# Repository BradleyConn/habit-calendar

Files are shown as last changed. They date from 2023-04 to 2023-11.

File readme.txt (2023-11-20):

This project contains everything used to construct a Habit Calender inspired from Simone Geirtz https://yetch.store/products/every-day-goal-calendar

This project contains the PCB designs designed in kicad as well as BOM and position files that wer sent off to JLCPCB for manufacturing.

Each board cost around $4 to make and ship and contains two PY32F002A microcontrollers and 32 lights/buttons. It takes 16 boards to make a full 365 day calendar.

The lights are ws2812b which provide endless lighting possibilities to be used outside of a calender concept. The LEDs can be controlled from the microcontroller with a bitbanged driver. A neat accomplishment from a super cheap 8 MHz microcontroller.

This wasn't intended to be public facing yet so the code is somewhat messy from when I was just trying to protoype stuff out, and documentation is not the best. In the software folder, the standalone folder is what you want, but check the readme for helpful info. Hopefully I can find some time to clean everything up.

More information and pictures can be found on www.bradleyconn.space
I need to properly cross link everything still. Sorry about that.

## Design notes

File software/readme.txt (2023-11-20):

Different project options. Just move the main.c file into the User folder in the submodule and build from there.

Use pico to load code onto board.
XXX: TO PROGRAM MUST CONNECT TO 3.3V!!! (Not 5V)
Connect pico pin GP3 to PA14
Connect pico pin GP2 to PA13
`sudo make flash`
erase with `sudo pyocd erase -t py32f002ax5 --chip --config ./Misc/pyocd.yaml`

may need to rebase the template submodule to 4c9de4301e8855a. That's where I was working from in development. New commits untested.

- Standalone has each micrcontroller controlling their own leds. No central control.
    - Probably only want to keep PF0 or PF1 resistors which connects micro to LED Din, remove the 7 others

(Work In Progress)
XXX: Turns out for the 002a version there's only tx or rx on a pin, not both... i2c could be an option if slave mode actually works but I'm unsure with the chinese datasheet. The english datasheet is for the 030 or 003 parts. Bitbang uart is probably the best option with interrupts for nonblocking. Probably ditch polling, and just have one way comms.
- Pico master, each micro gets polled for it's state over a uart chain and pico controls the LEDs 
    - Each micro needs a different ID
    - Top and bottom micro have different code (see below), but same code board to board (except for ID)
    - Remove all the micro<->LED resistors
    - Top micro remove PF0 resistor
        - Same board micro to micro half duplex over PF1
    - Bottom micro remove PF0 resistor
        - Board to board half duplex over PF0
    - So resistors should be
        - So no horizontal resistors
        - Top micro veritcal resistors should be DNP, DNP, P (boot), DNP, DNP, P (PF1)
        - Bottom micro veritcal resistors should be DNP, DNP, P (boot), DNP, P (PF0), DNP

- Pico master with wled option
    - wip but use a toggle switch to switch who controls the ws2812b line

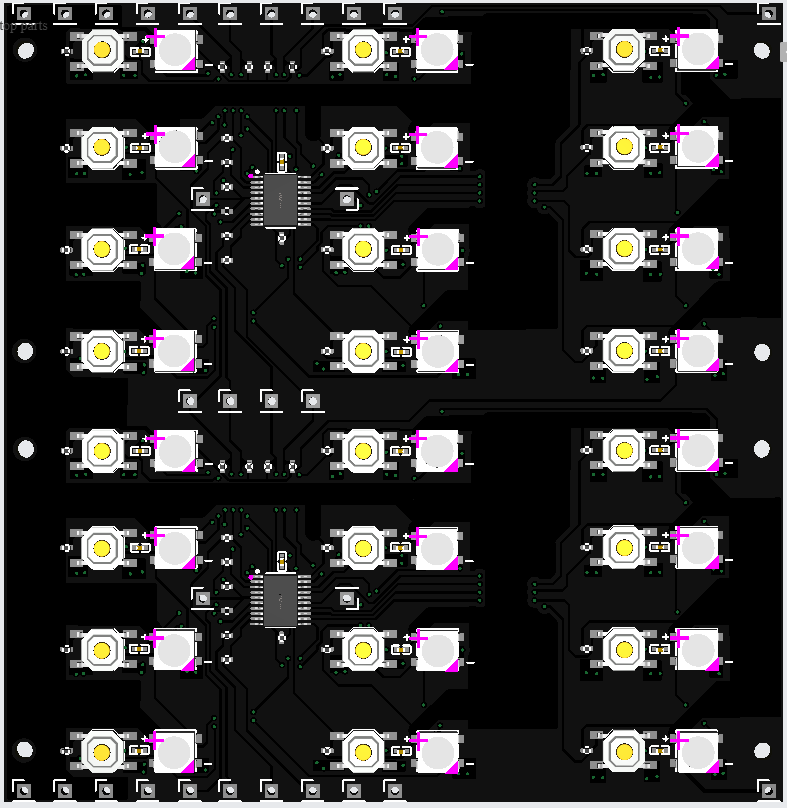
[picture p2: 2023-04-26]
images/3d-model-front.png

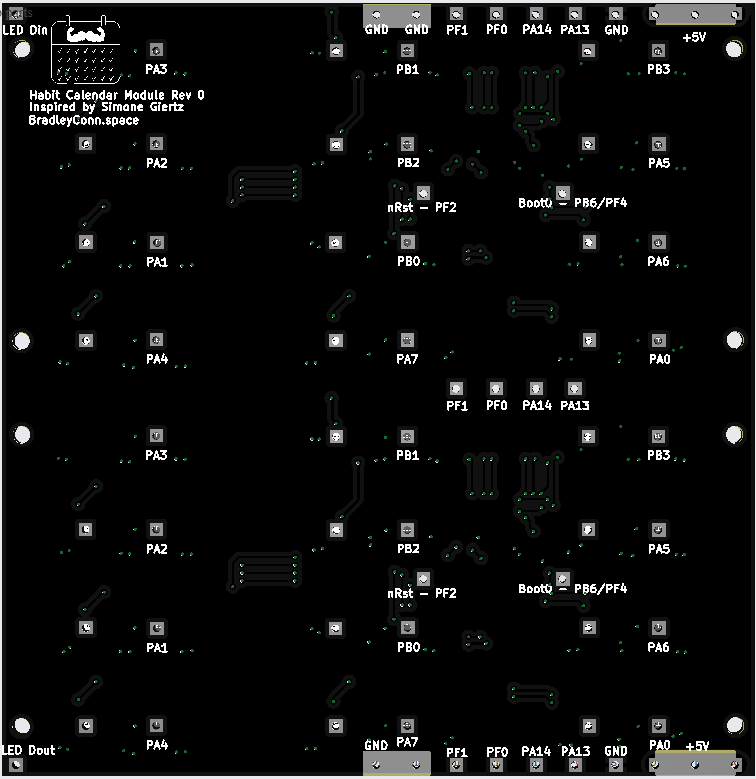
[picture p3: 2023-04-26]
images/3d-model-back.png

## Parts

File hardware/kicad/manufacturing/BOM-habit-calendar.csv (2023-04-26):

Comment | Designator | Footprint | LCSC
100nf | C1,C10,C11,C12,C14,C15,C16,C17,C18,C19,C2,C20,C21,C22,C23,C24,C25,C3,C4,C5,C6,C7,C8,C9 | C0402 | C1525
XL-5050RGBC-WS2812B | LED1,LED10,LED11,LED12,LED13,LED14,LED15,LED16,LED17,LED18,LED19,LED2,LED20,LED21,LED22,LED23,LED24,LED3,LED4,LED5,LED6,LED7,LED8,LED9 | LED-SMD_4P-L5.0-W5.0-BL_XL-5050RGBC | C2843785
TS-1187A-B-A-B | SW1,SW10,SW11,SW12,SW13,SW14,SW15,SW16,SW17,SW18,SW19,SW2,SW20,SW21,SW22,SW23,SW24,SW3,SW4,SW5,SW6,SW7,SW8,SW9 | SW-SMD_4P-L5.1-W5.1-P3.70-LS6.5-TL-2 | C318884
PY32F002AF15P6TU | U1,U2 | TSSOP-20_L6.5-W4.4-P0.65-LS6.4-BL | C5292059
Conn_01x01 | J78 | PinHeader_1x01_P2.54mm_Vertical
Conn_01x01 | J77 | PinHeader_1x01_P2.54mm_Vertical
Conn_01x01 | J76 | PinHeader_1x01_P2.54mm_Vertical
Conn_01x01 | J75 | PinHeader_1x01_P2.54mm_Vertical
10k | R46 | R_0402_1005Metric
10k | R45 | R_0402_1005Metric
0 ohm | R44 | R_0402_1005Metric
0 ohm | R43 | R_0402_1005Metric
0 ohm | R42 | R_0402_1005Metric
0 ohm | R41 | R_0402_1005Metric
10k | R40 | R_0402_1005Metric
10k | R39 | R_0402_1005Metric
10k | R38 | R_0402_1005Metric
10k | R37 | R_0402_1005Metric
10k | R36 | R_0402_1005Metric
10k | R35 | R_0402_1005Metric
10k | R34 | R_0402_1005Metric
10k | R33 | R_0402_1005Metric
DNP | R32 | R_0402_1005Metric
10k | R31 | R_0402_1005Metric
0 ohm | R30 | R_0402_1005Metric
0 ohm | R29 | R_0402_1005Metric
10k | R28 | R_0402_1005Metric
0 ohm | R27 | R_0402_1005Metric
0 ohm | R26 | R_0402_1005Metric
10k | R25 | R_0402_1005Metric
10k | R24 | R_0402_1005Metric
Conn_01x01 | J98 | PinHeader_1x01_P2.54mm_Vertical
Conn_01x01 | J97 | PinHeader_1x01_P2.54mm_Vertical
Conn_01x01 | J96 | PinHeader_1x01_P2.54mm_Vertical
Conn_01x01 | J95 | PinHeader_1x01_P2.54mm_Vertical
Conn_01x01 | J94 | PinHeader_1x01_P2.54mm_Vertical
Conn_01x01 | J93 | PinHeader_1x01_P2.54mm_Vertical
Conn_01x01 | J92 | PinHeader_1x01_P2.54mm_Vertical
Conn_01x01 | J91 | PinHeader_1x01_P2.54mm_Vertical
Conn_01x01 | J90 | PinHeader_1x01_P2.54mm_Vertical
Conn_01x01 | J89 | PinHeader_1x01_P2.54mm_Vertical
Conn_01x01 | J62 | PinHeader_1x01_P2.54mm_Vertical
Conn_01x01 | J61 | PinHeader_1x01_P2.54mm_Vertical
Conn_01x01 | J59 | PinHeader_1x01_P2.54mm_Vertical
Conn_01x01 | J58 | PinHeader_1x01_P2.54mm_Vertical
Conn_01x01 | J57 | PinHeader_1x01_P2.54mm_Vertical
Conn_01x01 | J56 | PinHeader_1x01_P2.54mm_Vertical
Conn_01x01 | J55 | PinHeader_1x01_P2.54mm_Vertical
Conn_01x01 | J54 | PinHeader_1x01_P2.54mm_Vertical
Conn_01x01 | J53 | PinHeader_1x01_P2.54mm_Vertical
Conn_01x01 | J52 | PinHeader_1x01_P2.54mm_Vertical
Conn_01x01 | J50 | PinHeader_1x01_P2.54mm_Vertical
Conn_01x01 | J49 | PinHeader_1x01_P2.54mm_Vertical
Conn_01x01 | J47 | PinHeader_1x01_P2.54mm_Vertical
Conn_01x01 | J46 | PinHeader_1x01_P2.54mm_Vertical
Conn_01x01 | J45 | PinHeader_1x01_P2.54mm_Vertical
Conn_01x01 | J44 | PinHeader_1x01_P2.54mm_Vertical
Conn_01x01 | J43 | PinHeader_1x01_P2.54mm_Vertical
Conn_01x01 | J41 | PinHeader_1x01_P2.54mm_Vertical
Conn_01x01 | J40 | PinHeader_1x01_P2.54mm_Vertical
Conn_01x01 | J38 | PinHeader_1x01_P2.54mm_Vertical
Conn_01x01 | J37 | PinHeader_1x01_P2.54mm_Vertical
Conn_01x01 | J36 | PinHeader_1x01_P2.54mm_Vertical
Conn_01x01 | J35 | PinHeader_1x01_P2.54mm_Vertical
Conn_01x01 | J34 | PinHeader_1x01_P2.54mm_Vertical
Conn_01x01 | J33 | PinHeader_1x01_P2.54mm_Vertical
Conn_01x01 | J32 | PinHeader_1x01_P2.54mm_Vertical
MountingHole | H8 | MountingHole_2.2mm_M2
MountingHole | H7 | MountingHole_2.2mm_M2
MountingHole | H6 | MountingHole_2.2mm_M2
MountingHole | H5 | MountingHole_2.2mm_M2
100nf | C26 | C0402
Conn_01x01 | J10 | PinHeader_1x01_P2.54mm_Vertical
10k | R19 | R_0402_1005Metric
Conn_01x01 | J63 | PinHeader_1x01_P2.54mm_Vertical
Conn_01x01 | J67 | PinHeader_1x01_P2.54mm_Vertical
Conn_01x01 | J21 | PinHeader_1x01_P2.54mm_Vertical
Conn_01x01 | J5 | PinHeader_1x01_P2.54mm_Vertical
Conn_01x01 | J15 | PinHeader_1x01_P2.54mm_Vertical
10k | R9 | R_0402_1005Metric
0 ohm | R22 | R_0402_1005Metric
Conn_01x01 | J9 | PinHeader_1x01_P2.54mm_Vertical
10k | R13 | R_0402_1005Metric
0 ohm | R14 | R_0402_1005Metric
Conn_01x01 | J2 | PinHeader_1x01_P2.54mm_Vertical
Conn_01x01 | J20 | PinHeader_1x01_P2.54mm_Vertical
Conn_01x01 | J30 | PinHeader_1x01_P2.54mm_Vertical
Conn_01x01 | J22 | PinHeader_1x01_P2.54mm_Vertical
Conn_01x01 | J13 | PinHeader_1x01_P2.54mm_Vertical
10k | R8 | R_0402_1005Metric
Conn_01x01 | J31 | PinHeader_1x01_P2.54mm_Vertical
Conn_01x01 | J11 | PinHeader_1x01_P2.54mm_Vertical
MountingHole | H1 | MountingHole_2.2mm_M2
Conn_01x01 | J1 | PinHeader_1x01_P2.54mm_Vertical
Conn_01x01 | J66 | PinHeader_1x01_P2.54mm_Vertical
MountingHole | H2 | MountingHole_2.2mm_M2
MountingHole | H3 | MountingHole_2.2mm_M2
0 ohm | R20 | R_0402_1005Metric
Conn_01x01 | J29 | PinHeader_1x01_P2.54mm_Vertical
10k | R2 | R_0402_1005Metric
10k | R10 | R_0402_1005Metric
10k | R18 | R_0402_1005Metric
10k | R11 | R_0402_1005Metric
Conn_01x01 | J4 | PinHeader_1x01_P2.54mm_Vertical
100nf | C13 | C0402
Conn_01x01 | J65 | PinHeader_1x01_P2.54mm_Vertical
DNP | R7 | R_0402_1005Metric
Conn_01x01 | J18 | PinHeader_1x01_P2.54mm_Vertical
MountingHole | H4 | MountingHole_2.2mm_M2
0 ohm | R12 | R_0402_1005Metric
Conn_01x01 | J27 | PinHeader_1x01_P2.54mm_Vertical
10k | R17 | R_0402_1005Metric
10k | R1 | R_0402_1005Metric
Conn_01x01 | J6 | PinHeader_1x01_P2.54mm_Vertical
0 ohm | R23 | R_0402_1005Metric
Conn_01x01 | J25 | PinHeader_1x01_P2.54mm_Vertical
0 ohm | R4 | R_0402_1005Metric
Conn_01x01 | J26 | PinHeader_1x01_P2.54mm_Vertical
Conn_01x01 | J16 | PinHeader_1x01_P2.54mm_Vertical
10k | R16 | R_0402_1005Metric
Conn_01x01 | J64 | PinHeader_1x01_P2.54mm_Vertical
10k | R6 | R_0402_1005Metric
Conn_01x01 | J51 | PinHeader_1x01_P2.54mm_Vertical
Conn_01x01 | J12 | PinHeader_1x01_P2.54mm_Vertical
Conn_01x01 | J68 | PinHeader_1x01_P2.54mm_Vertical
Conn_01x01 | J24 | PinHeader_1x01_P2.54mm_Vertical
0 ohm | R21 | R_0402_1005Metric
10k | R15 | R_0402_1005Metric
Conn_01x01 | J60 | PinHeader_1x01_P2.54mm_Vertical
Conn_01x01 | J17 | PinHeader_1x01_P2.54mm_Vertical
Conn_01x01 | J8 | PinHeader_1x01_P2.54mm_Vertical
0 ohm | R5 | R_0402_1005Metric
10k | R3 | R_0402_1005Metric
Conn_01x01 | J7 | PinHeader_1x01_P2.54mm_Vertical
Conn_01x01 | J19 | PinHeader_1x01_P2.54mm_Vertical
Conn_01x01 | J14 | PinHeader_1x01_P2.54mm_Vertical

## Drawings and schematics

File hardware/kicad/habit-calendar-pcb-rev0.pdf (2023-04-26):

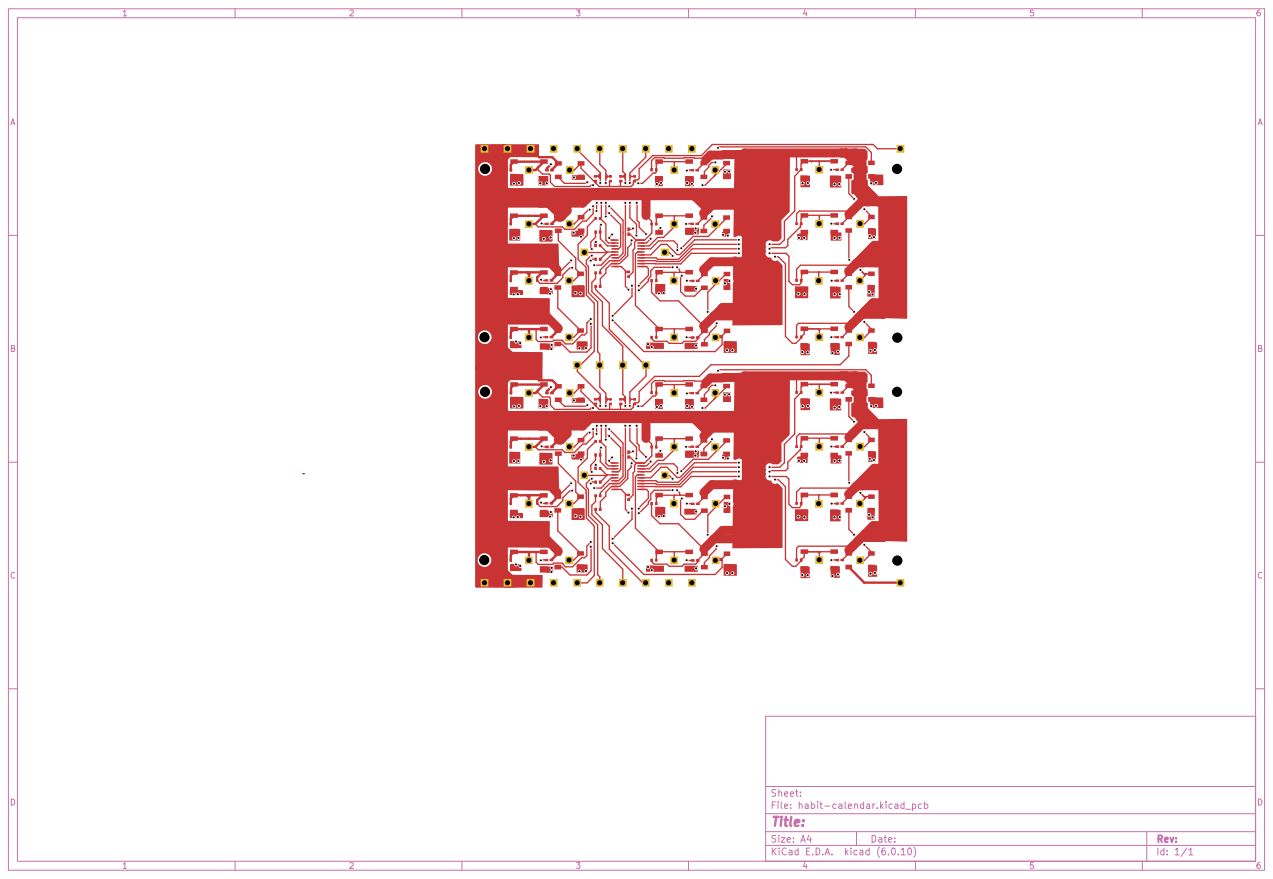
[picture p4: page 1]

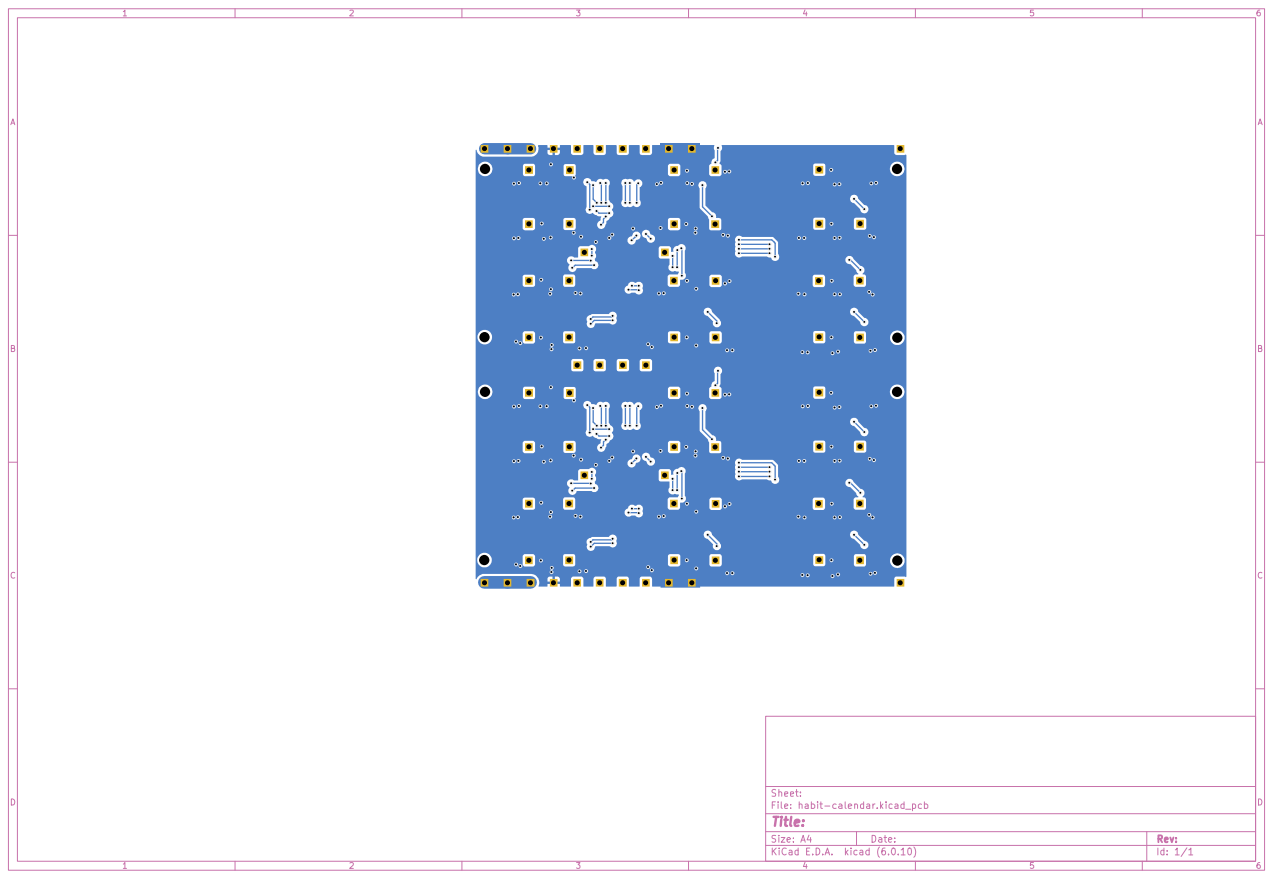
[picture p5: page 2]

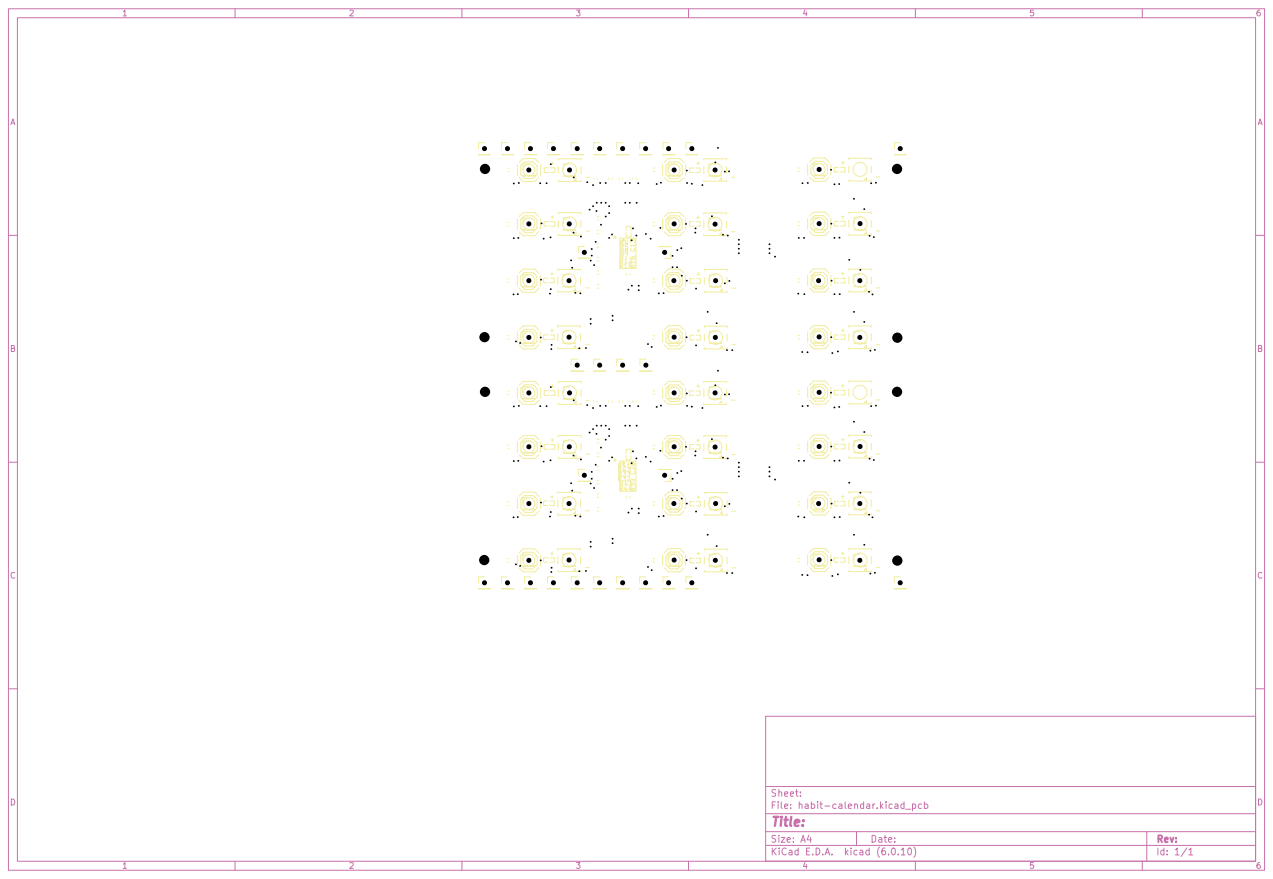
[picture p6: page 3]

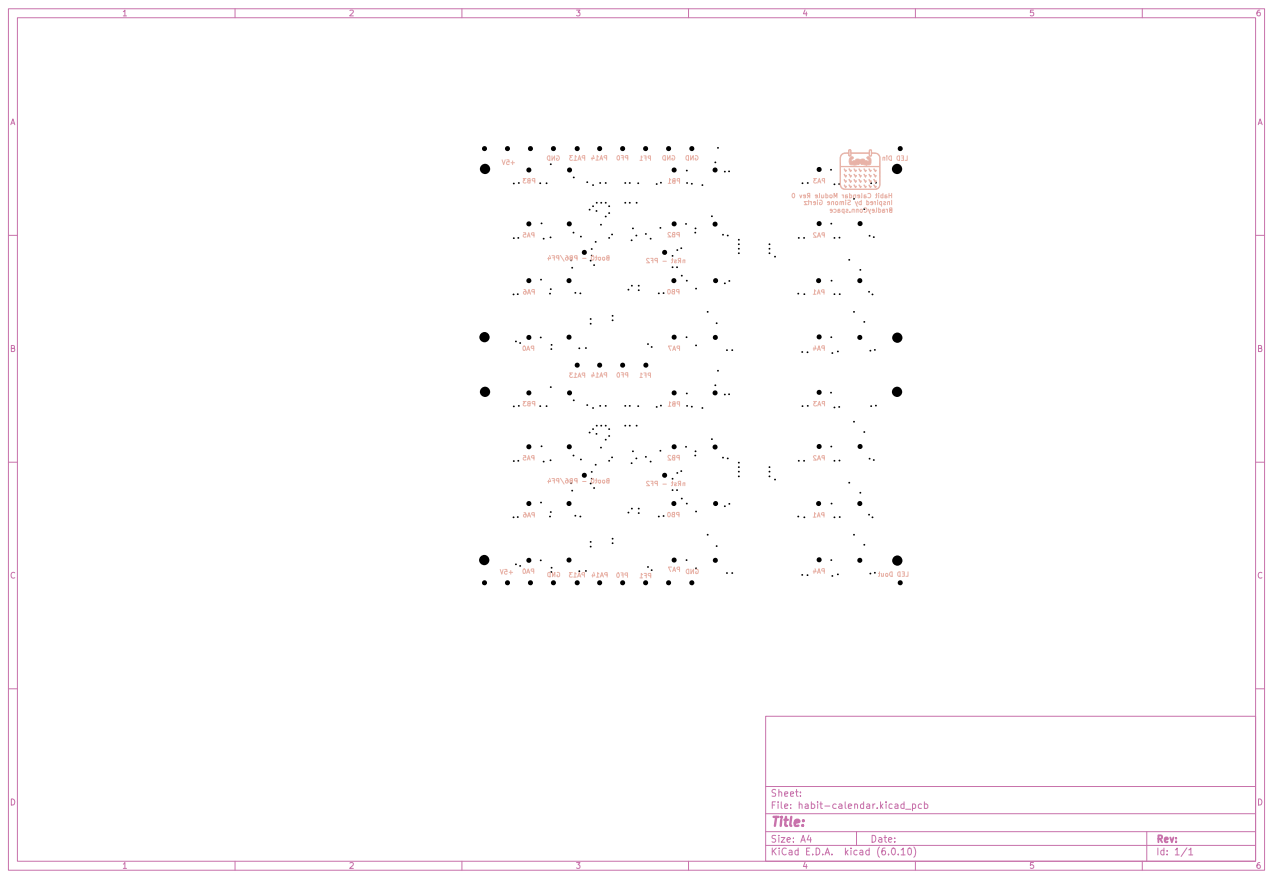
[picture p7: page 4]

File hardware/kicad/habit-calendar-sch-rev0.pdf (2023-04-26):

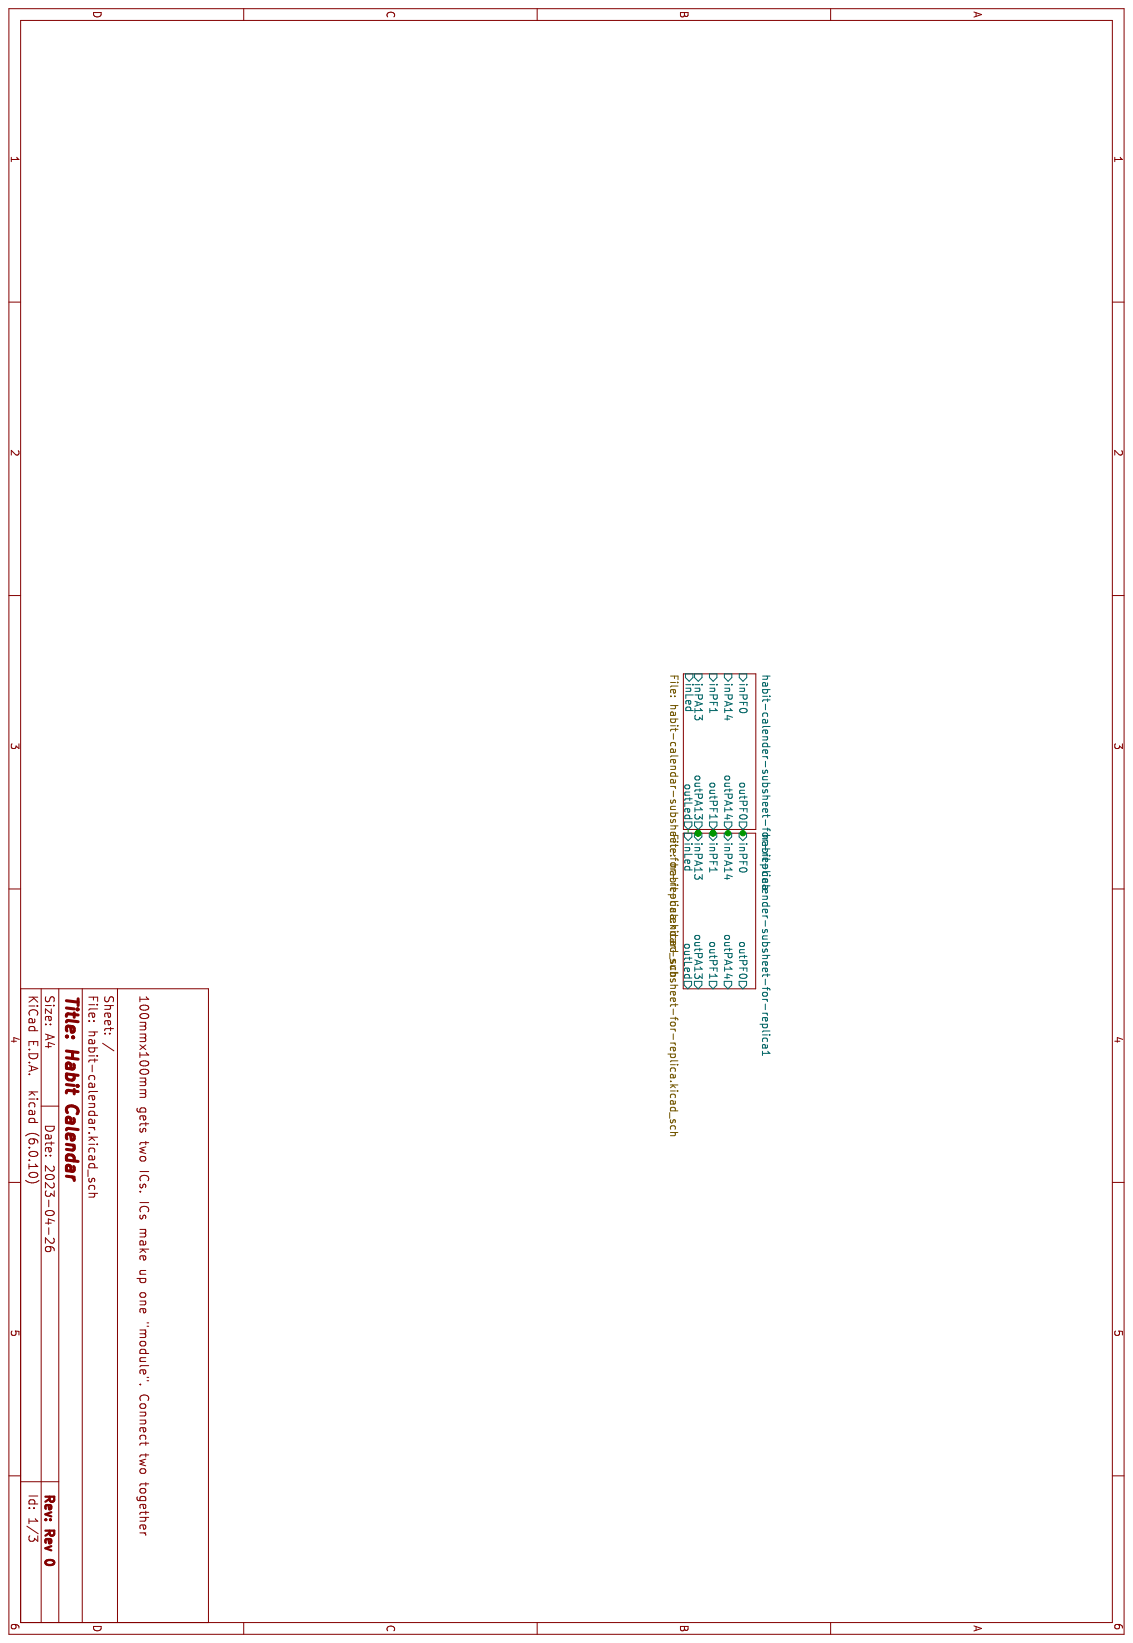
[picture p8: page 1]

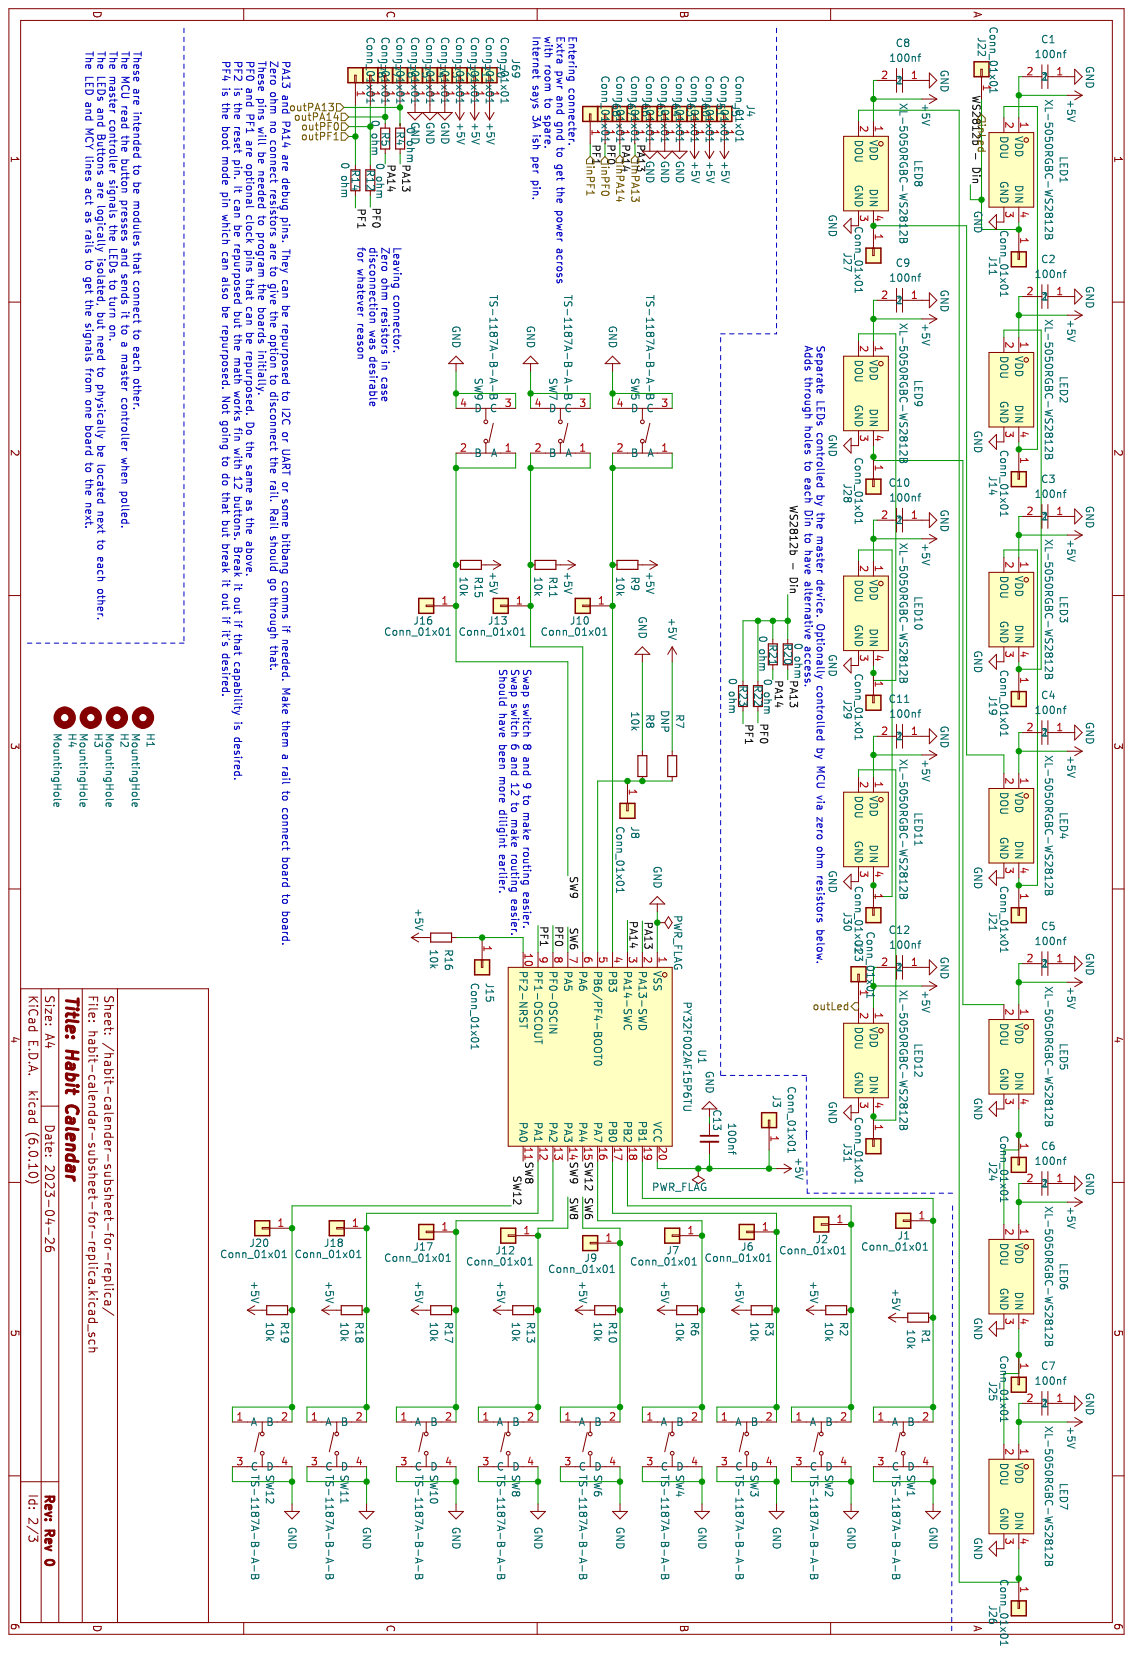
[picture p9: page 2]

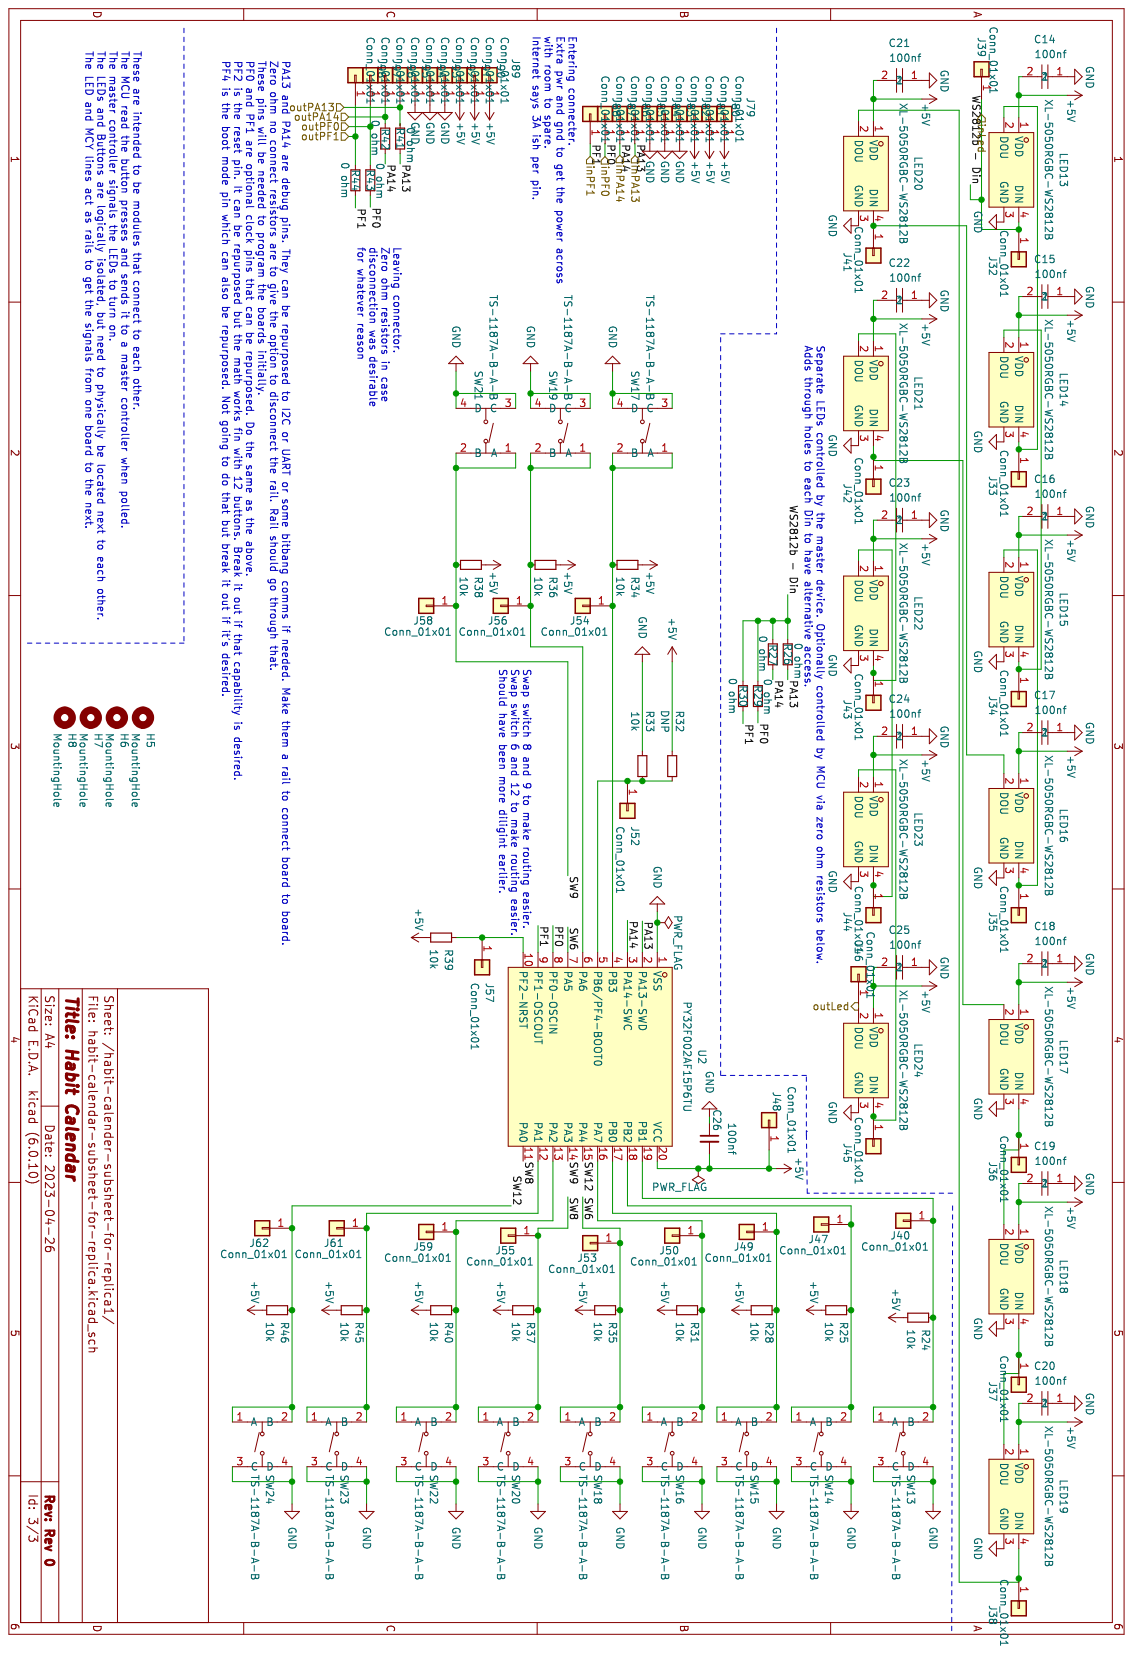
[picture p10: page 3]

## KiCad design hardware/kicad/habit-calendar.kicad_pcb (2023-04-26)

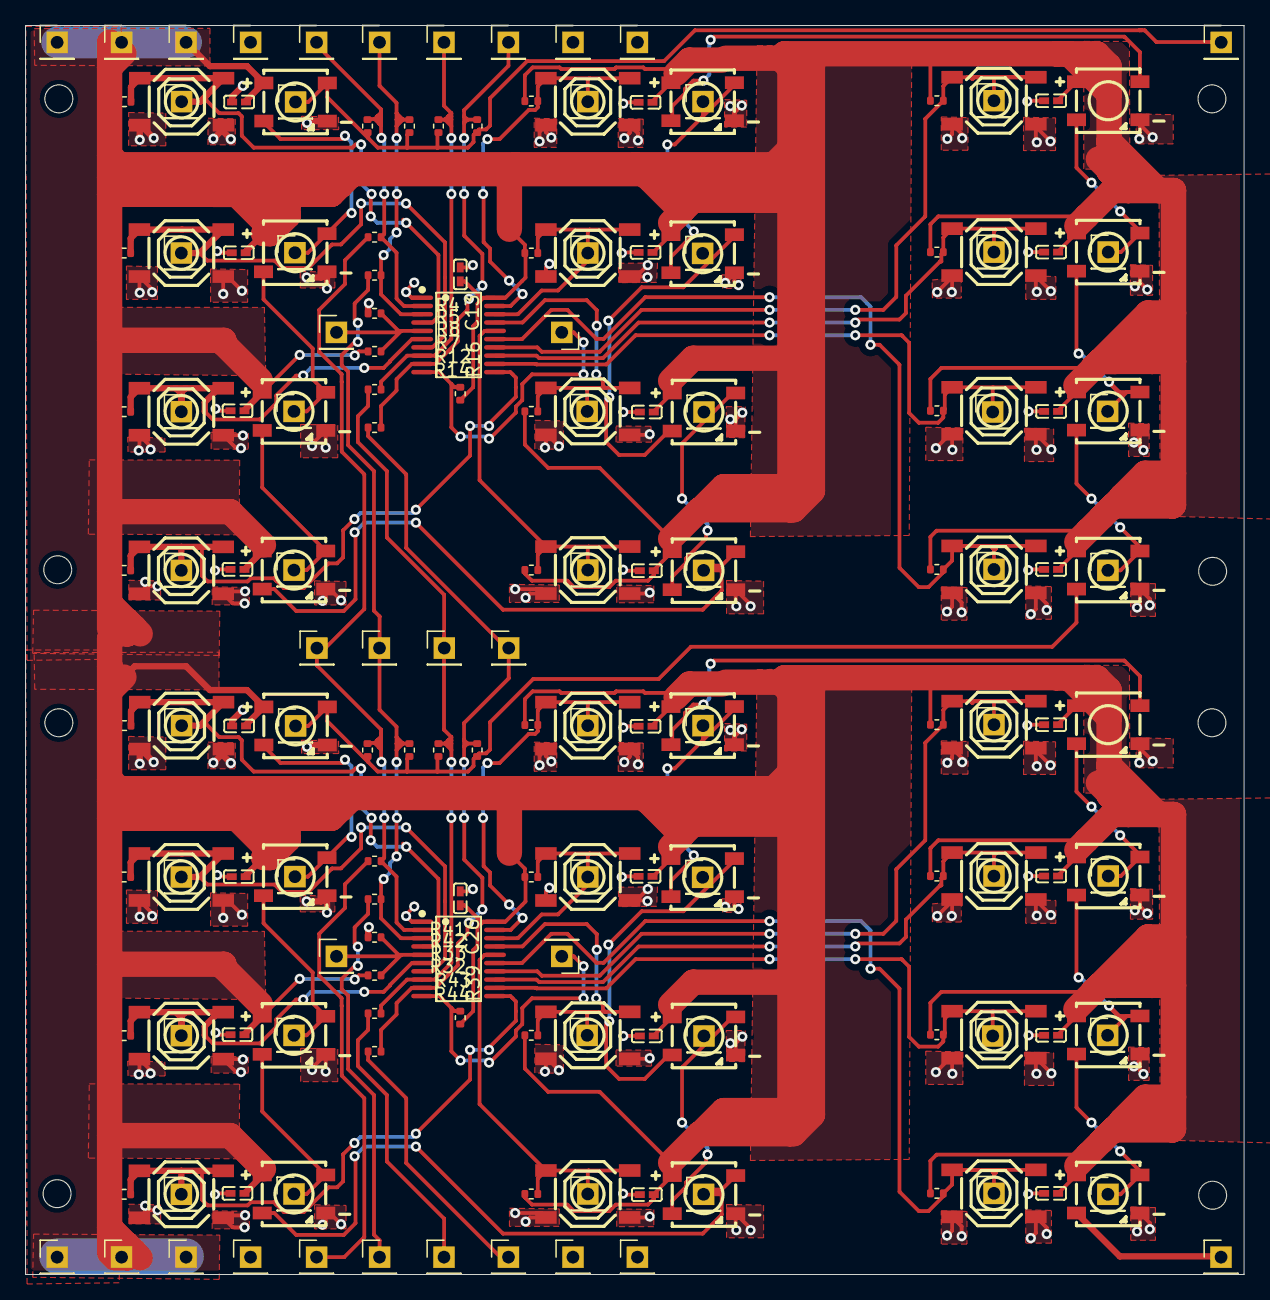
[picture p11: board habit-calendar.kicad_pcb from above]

Board: 2 copper layers, 96.0 x 98.4 mm, 206 parts (0 on the bottom side), 67 nets.

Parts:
C1, C2, C3, C4, C5, C6, C7, C8, C9, C10, C11, C12, C13, C14, C15, C16, C17, C18, C19, C20, C21, C22, C23, C24, C25, C26: 100nf; C0402
H1, H2, H3, H4, H5, H6, H7, H8: MountingHole; MountingHole_2.2mm_M2
J1, J2, J4, J5, J6, J7, J8, J9, J10, J11, J12, J13, J14, J15, J16, J17, J18, J19, J20, J21, J22, J24, J25, J26, J27, J29, J30, J31, J32, J33, J34, J35, J36, J37, J38, J40, J41, J43, J44, J45, J46, J47, J49, J50, J51, J52, J53, J54, J55, J56, J57, J58, J59, J60, J61, J62, J63, J64, J65, J66, J67, J68, J75, J76, J77, J78, J89, J90, J91, J92, J93, J94, J95, J96, J97, J98: Conn_01x01; PinHeader_1x01_P2.54mm_Vertical
LED1, LED2, LED3, LED4, LED5, LED6, LED7, LED8, LED9, LED10, LED11, LED12, LED13, LED14, LED15, LED16, LED17, LED18, LED19, LED20, LED21, LED22, LED23, LED24: XL-5050RGBC-WS2812B; LED-SMD_4P-L5.0-W5.0-BL_XL-5050RGBC
R1, R2, R3, R6, R8, R9, R10, R11, R13, R15, R16, R17, R18, R19, R24, R25, R28, R31, R33, R34, R35, R36, R37, R38, R39, R40, R45, R46: 10k; R_0402_1005Metric
R4, R5, R12, R14, R20, R21, R22, R23, R26, R27, R29, R30, R41, R42, R43, R44: 0 ohm; R_0402_1005Metric
R7, R32: DNP; R_0402_1005Metric
SW1, SW2, SW3, SW4, SW5, SW6, SW7, SW8, SW9, SW10, SW11, SW12, SW13, SW14, SW15, SW16, SW17, SW18, SW19, SW20, SW21, SW22, SW23, SW24: TS-1187A-B-A-B; SW-SMD_4P-L5.1-W5.1-P3.70-LS6.5-TL-2
U1, U2: PY32F002AF15P6TU; TSSOP-20_L6.5-W4.4-P0.65-LS6.4-BL

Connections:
+5V: C1.2, C2.2, C3.2, C4.2, C5.2, C6.2, C7.2, C8.2, C9.2, C10.2, C11.2, C12.2, C13.2, C14.2, C15.2, C16.2, C17.2, C18.2, C19.2, C20.2, C21.2, C22.2, C23.2, C24.2, C25.2, C26.2, J4.1, J5.1, J51.1, J89.1, J90.1, J91.1, LED1.1 (VDD), LED2.1 (VDD), LED3.1 (VDD), LED4.1 (VDD), LED5.1 (VDD), LED6.1 (VDD), LED7.1 (VDD), LED8.1 (VDD), LED9.1 (VDD), LED10.1 (VDD), LED11.1 (VDD), LED12.1 (VDD), LED13.1 (VDD), LED14.1 (VDD), LED15.1 (VDD), LED16.1 (VDD), LED17.1 (VDD), LED18.1 (VDD), LED19.1 (VDD), LED20.1 (VDD), LED21.1 (VDD), LED22.1 (VDD), LED23.1 (VDD), LED24.1 (VDD), R1.2, R2.2, R3.2, R6.2, R7.1, R9.2, R10.2, R11.2, R13.2, R15.2, R16.2, R17.2, R18.2, R19.2, R24.2, R25.2, R28.2, R31.2, R32.1, R34.2, R35.2, R36.2, R37.2, R38.2, R39.2, R40.2, R45.2, R46.2, U1.20 (VCC), U2.20 (VCC)
/habit-calender-subsheet-for-replica1/PA13: J75.1, R4.1, R26.2, R41.2, U2.2 (PA13-SWD)
/habit-calender-subsheet-for-replica1/PA14: J76.1, R5.1, R27.2, R42.2, U2.3 (PA14-SWC)
/habit-calender-subsheet-for-replica1/PF0: J77.1, R12.1, R29.2, R43.2, U2.8 (PF0-OSCIN)
/habit-calender-subsheet-for-replica1/PF1: J78.1, R14.1, R30.2, R44.2, U2.9 (PF1-OSCOUT)
/habit-calender-subsheet-for-replica1/SW6: J53.1, R35.1, SW18.1 (A), SW18.2 (B), U2.7 (PA5)
/habit-calender-subsheet-for-replica1/SW8: J55.1, R37.1, SW20.1 (A), SW20.2 (B), U2.11 (PA0)
/habit-calender-subsheet-for-replica1/SW9: J58.1, R38.1, SW21.1 (A), SW21.2 (B), U2.14 (PA3)
/habit-calender-subsheet-for-replica1/SW12: J62.1, R46.1, SW24.1 (A), SW24.2 (B), U2.15 (PA4)
/habit-calender-subsheet-for-replica1/WS2812b - Din: J32.1, LED12.2 (DOU), LED13.4 (DIN), R26.1, R27.1, R29.1, R30.1
/habit-calender-subsheet-for-replica1/outLed: J46.1, LED24.2 (DOU)
/habit-calender-subsheet-for-replica1/outPA13: J95.1, R41.1
/habit-calender-subsheet-for-replica1/outPA14: J96.1, R42.1
/habit-calender-subsheet-for-replica1/outPF0: J97.1, R43.1
/habit-calender-subsheet-for-replica1/outPF1: J98.1, R44.1
/habit-calender-subsheet-for-replica/PA13: J65.1, R4.2, R20.2, U1.2 (PA13-SWD)
/habit-calender-subsheet-for-replica/PA14: J66.1, R5.2, R21.2, U1.3 (PA14-SWC)
/habit-calender-subsheet-for-replica/PF0: J67.1, R12.2, R22.2, U1.8 (PF0-OSCIN)
/habit-calender-subsheet-for-replica/PF1: J68.1, R14.2, R23.2, U1.9 (PF1-OSCOUT)
/habit-calender-subsheet-for-replica/SW6: J9.1, R10.1, SW6.1 (A), SW6.2 (B), U1.7 (PA5)
/habit-calender-subsheet-for-replica/SW8: J12.1, R13.1, SW8.1 (A), SW8.2 (B), U1.11 (PA0)
/habit-calender-subsheet-for-replica/SW9: J16.1, R15.1, SW9.1 (A), SW9.2 (B), U1.14 (PA3)
/habit-calender-subsheet-for-replica/SW12: J20.1, R19.1, SW12.1 (A), SW12.2 (B), U1.15 (PA4)
/habit-calender-subsheet-for-replica/WS2812b - Din: J11.1, J22.1, LED1.4 (DIN), R20.1, R21.1, R22.1, R23.1
GND: C1.1, C2.1, C3.1, C4.1, C5.1, C6.1, C7.1, C8.1, C9.1, C10.1, C11.1, C12.1, C13.1, C14.1, C15.1, C16.1, C17.1, C18.1, C19.1, C20.1, C21.1, C22.1, C23.1, C24.1, C25.1, C26.1, J60.1, J63.1, J64.1, J92.1, J93.1, J94.1, LED1.3 (GND), LED2.3 (GND), LED3.3 (GND), LED4.3 (GND), LED5.3 (GND), LED6.3 (GND), LED7.3 (GND), LED8.3 (GND), LED9.3 (GND), LED10.3 (GND), LED11.3 (GND), LED12.3 (GND), LED13.3 (GND), LED14.3 (GND), LED15.3 (GND), LED16.3 (GND), LED17.3 (GND), LED18.3 (GND), LED19.3 (GND), LED20.3 (GND), LED21.3 (GND), LED22.3 (GND), LED23.3 (GND), LED24.3 (GND), R8.1, R33.1, SW1.3 (C), SW1.4 (D), SW2.3 (C), SW2.4 (D), SW3.3 (C), SW3.4 (D), SW4.3 (C), SW4.4 (D), SW5.3 (C), SW5.4 (D), SW6.3 (C), SW6.4 (D), SW7.3 (C), SW7.4 (D), SW8.3 (C), SW8.4 (D), SW9.3 (C), SW9.4 (D), SW10.3 (C), SW10.4 (D), SW11.3 (C), SW11.4 (D), SW12.3 (C), SW12.4 (D), SW13.3 (C), SW13.4 (D), SW14.3 (C), SW14.4 (D), SW15.3 (C), SW15.4 (D), SW16.3 (C), SW16.4 (D), SW17.3 (C), SW17.4 (D), SW18.3 (C), SW18.4 (D), SW19.3 (C), SW19.4 (D), SW20.3 (C), SW20.4 (D), SW21.3 (C), SW21.4 (D), SW22.3 (C), SW22.4 (D), SW23.3 (C), SW23.4 (D), SW24.3 (C), SW24.4 (D), U1.1 (VSS), U2.1 (VSS)
unnamed: J1.1, R1.1, SW1.1 (A), SW1.2 (B), U1.19 (PB1)
unnamed: J2.1, R2.1, SW2.1 (A), SW2.2 (B), U1.18 (PB2)
unnamed: J6.1, R3.1, SW3.1 (A), SW3.2 (B), U1.17 (PB0)
unnamed: J7.1, R6.1, SW4.1 (A), SW4.2 (B), U1.16 (PA7)
unnamed: J8.1, R7.2, R8.2, U1.5 (PB6/PF4-BOOT0)
unnamed: J10.1, R9.1, SW5.1 (A), SW5.2 (B), U1.4 (PB3)
unnamed: J13.1, R11.1, SW7.1 (A), SW7.2 (B), U1.6 (PA6)
unnamed: J14.1, LED1.2 (DOU), LED2.4 (DIN)
unnamed: J15.1, R16.1, U1.10 (PF2-NRST)
unnamed: J17.1, R17.1, SW10.1 (A), SW10.2 (B), U1.13 (PA2)
unnamed: J18.1, R18.1, SW11.1 (A), SW11.2 (B), U1.12 (PA1)
unnamed: J19.1, LED2.2 (DOU), LED3.4 (DIN)
unnamed: J21.1, LED3.2 (DOU), LED4.4 (DIN)
unnamed: J24.1, LED5.4 (DIN), LED6.2 (DOU)
unnamed: J25.1, LED6.4 (DIN), LED7.2 (DOU)
unnamed: J26.1, LED7.4 (DIN), LED8.2 (DOU)
unnamed: J27.1, LED4.2 (DOU), LED8.4 (DIN)
unnamed: LED5.2 (DOU), LED9.4 (DIN)
unnamed: J29.1, LED9.2 (DOU), LED10.4 (DIN)
unnamed: J30.1, LED10.2 (DOU), LED11.4 (DIN)
unnamed: J31.1, LED11.2 (DOU), LED12.4 (DIN)
unnamed: J33.1, LED13.2 (DOU), LED14.4 (DIN)
unnamed: J34.1, LED14.2 (DOU), LED15.4 (DIN)
unnamed: J35.1, LED15.2 (DOU), LED16.4 (DIN)
unnamed: J36.1, LED17.4 (DIN), LED18.2 (DOU)
unnamed: J37.1, LED18.4 (DIN), LED19.2 (DOU)
unnamed: J38.1, LED19.4 (DIN), LED20.2 (DOU)
unnamed: J40.1, R24.1, SW13.1 (A), SW13.2 (B), U2.19 (PB1)
unnamed: J41.1, LED16.2 (DOU), LED20.4 (DIN)
unnamed: LED17.2 (DOU), LED21.4 (DIN)
unnamed: J43.1, LED21.2 (DOU), LED22.4 (DIN)
unnamed: J44.1, LED22.2 (DOU), LED23.4 (DIN)
unnamed: J45.1, LED23.2 (DOU), LED24.4 (DIN)
unnamed: J47.1, R25.1, SW14.1 (A), SW14.2 (B), U2.18 (PB2)
unnamed: J49.1, R28.1, SW15.1 (A), SW15.2 (B), U2.17 (PB0)
unnamed: J50.1, R31.1, SW16.1 (A), SW16.2 (B), U2.16 (PA7)
unnamed: J52.1, R32.2, R33.2, U2.5 (PB6/PF4-BOOT0)
unnamed: J54.1, R34.1, SW17.1 (A), SW17.2 (B), U2.4 (PB3)
unnamed: J56.1, R36.1, SW19.1 (A), SW19.2 (B), U2.6 (PA6)
unnamed: J57.1, R39.1, U2.10 (PF2-NRST)
unnamed: J59.1, R40.1, SW22.1 (A), SW22.2 (B), U2.13 (PA2)
unnamed: J61.1, R45.1, SW23.1 (A), SW23.2 (B), U2.12 (PA1)

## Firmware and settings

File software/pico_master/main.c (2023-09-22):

/* Includes ------------------------------------------------------------------*/
#include "py32f0xx_bsp_printf.h"
#include "py32f0xx_hal.h"
#include <stdbool.h>
#include <stdint.h>

/* Private define ------------------------------------------------------------*/
#define DEBUG 1
#define CALENDAR_CHIP_ID 7
#define MAX_CALENDAR_CHIP_ID 7
#define FLASH_USER_START_ADDR 0x08004000
#define FLASH_USER_START_ADDR_REDUNDANT 0x08003000
#define SETTING_SIZE 64
#define NUM_BUTTONS 12
#define BRIGHTNESS_INDEX 13
#define SPEED_INDEX 14
#define COLOR_INDEX 15
#define NUM_COLORS 13
#define RAINBOW_MODE_INDEX 16
#define FLASHVALID_INDEX 17
#define VALID_FLAG 0xaa
#define MAX_BRIGHTNESS 0x0F
#define NUM_SPEED_SETTINGS 0x08

// 10200 works for 9600 baud
#define BAUD_RATE (10300)

#define CALENDAR_FRONT_UART_PIN GPIO_PIN_7
#define CALENDAR_FRONT_UART_MODULE GPIOA

#define CALENDAR_BACK_UART_PIN GPIO_PIN_1
#define CALENDAR_BACK_UART_MODULE GPIOF

#if 0
#if CALENDAR_CHIP_ID % 2 == 0
#define CALENDAR_FRONT_UART_PIN GPIO_PIN_0
#define CALENDAR_FRONT_UART_MODULE GPIOF
#define CALENDAR_BACK_UART_PIN GPIO_PIN_1
#define CALENDAR_BACK_UART_MODULE GPIOF
#else
#define CALENDAR_FRONT_UART_PIN GPIO_PIN_1
#define CALENDAR_FRONT_UART_MODULE GPIOF
#define CALENDAR_BACK_UART_PIN GPIO_PIN_0
#define CALENDAR_BACK_UART_MODULE GPIOF
#endif
#endif

typedef enum { front = 0,
               back = 1 } front_back;
typedef enum { tx = 0,
               rx = 1 } tx_rx;

/* Private variables ---------------------------------------------------------*/
uint32_t Settings[SETTING_SIZE];
uint32_t Button_held[NUM_BUTTONS];
bool flash_needs_update = false;
uint8_t payload[64];
/* Private user code ---------------------------------------------------------*/
/* Private macro -------------------------------------------------------------*/
/* Private function prototypes -----------------------------------------------*/
static void APP_SystemClockConfig(void);
static void APP_LedConfig(void);
static void APP_FlashErase(uint8_t page);
static void APP_FlashProgram(uint8_t page);
static void APP_ErrorHandler(void);
static void init_buttons(void);
static void button_helper(uint8_t id, GPIO_PinState status);
static void check_buttons(void);
static void sleep_us(uint32_t us);
// Turn into front interface back interface
static void uart_init(front_back fb, tx_rx txrx);
static void uart_send_byte(front_back fb, uint8_t data);
static uint8_t uart_rx_byte(front_back fb);

static void uart_print_byte(uint8_t data);

inline void zero()
{
    GPIOF->BSRR = (uint32_t)GPIO_PIN_0;
    GPIOF->BSRR = (uint32_t)GPIO_PIN_0;
    GPIOF->BSRR = (uint32_t)GPIO_PIN_0;
    GPIOF->BSRR = (uint32_t)GPIO_PIN_0;
    GPIOF->BSRR = (uint32_t)GPIO_PIN_0;
    GPIOF->BSRR = (uint32_t)GPIO_PIN_0;
    GPIOF->BSRR = (uint32_t)GPIO_PIN_0;
    GPIOF->BSRR = (uint32_t)GPIO_PIN_0;
    GPIOF->BSRR = (uint32_t)GPIO_PIN_0;
    GPIOF->BRR = (uint32_t)GPIO_PIN_0;
    GPIOF->BRR = (uint32_t)GPIO_PIN_0;
    GPIOF->BRR = (uint32_t)GPIO_PIN_0;
    GPIOF->BRR = (uint32_t)GPIO_PIN_0;
    GPIOF->BRR = (uint32_t)GPIO_PIN_0;
    GPIOF->BRR = (uint32_t)GPIO_PIN_0;
    GPIOF->BRR = (uint32_t)GPIO_PIN_0;
    GPIOF->BRR = (uint32_t)GPIO_PIN_0;
    GPIOF->BRR = (uint32_t)GPIO_PIN_0;
    GPIOF->BRR = (uint32_t)GPIO_PIN_0;
    GPIOF->BRR = (uint32_t)GPIO_PIN_0;
    GPIOF->BRR = (uint32_t)GPIO_PIN_0;
    GPIOF->BRR = (uint32_t)GPIO_PIN_0;
    GPIOF->BRR = (uint32_t)GPIO_PIN_0;
    GPIOF->BRR = (uint32_t)GPIO_PIN_0;
    GPIOF->BRR = (uint32_t)GPIO_PIN_0;
    GPIOF->BRR = (uint32_t)GPIO_PIN_0;
    GPIOF->BRR = (uint32_t)GPIO_PIN_0;
    GPIOF->BRR = (uint32_t)GPIO_PIN_0;
    GPIOF->BRR = (uint32_t)GPIO_PIN_0;
    GPIOF->BRR = (uint32_t)GPIO_PIN_0;
}
inline void one()
{
    GPIOF->BSRR = (uint32_t)GPIO_PIN_0;
    GPIOF->BSRR = (uint32_t)GPIO_PIN_0;
    GPIOF->BSRR = (uint32_t)GPIO_PIN_0;
    GPIOF->BSRR = (uint32_t)GPIO_PIN_0;
    GPIOF->BSRR = (uint32_t)GPIO_PIN_0;
    GPIOF->BSRR = (uint32_t)GPIO_PIN_0;
    GPIOF->BSRR = (uint32_t)GPIO_PIN_0;
    GPIOF->BSRR = (uint32_t)GPIO_PIN_0;
    GPIOF->BSRR = (uint32_t)GPIO_PIN_0;
    GPIOF->BSRR = (uint32_t)GPIO_PIN_0;
    GPIOF->BSRR = (uint32_t)GPIO_PIN_0;
    GPIOF->BSRR = (uint32_t)GPIO_PIN_0;
    GPIOF->BSRR = (uint32_t)GPIO_PIN_0;
    GPIOF->BSRR = (uint32_t)GPIO_PIN_0;
    GPIOF->BSRR = (uint32_t)GPIO_PIN_0;
    GPIOF->BSRR = (uint32_t)GPIO_PIN_0;
    GPIOF->BSRR = (uint32_t)GPIO_PIN_0;
    GPIOF->BSRR = (uint32_t)GPIO_PIN_0;
    GPIOF->BSRR = (uint32_t)GPIO_PIN_0;
    GPIOF->BSRR = (uint32_t)GPIO_PIN_0;
    GPIOF->BSRR = (uint32_t)GPIO_PIN_0;
    GPIOF->BRR = (uint32_t)GPIO_PIN_0;
    GPIOF->BRR = (uint32_t)GPIO_PIN_0;
    GPIOF->BRR = (uint32_t)GPIO_PIN_0;
    GPIOF->BRR = (uint32_t)GPIO_PIN_0;
    GPIOF->BRR = (uint32_t)GPIO_PIN_0;
    GPIOF->BRR = (uint32_t)GPIO_PIN_0;
    GPIOF->BRR = (uint32_t)GPIO_PIN_0;
    GPIOF->BRR = (uint32_t)GPIO_PIN_0;
    GPIOF->BRR = (uint32_t)GPIO_PIN_0;
}

inline void send_byte(uint8_t byte)
{
    for (int b = 0; b < 8; b++) {
        if (byte & 0x80) {
            one();
        } else {
            zero();
        }
        byte = byte << 1;
    }
}

void update_flash()
{
    // Primary
    HAL_Delay(1);
    HAL_FLASH_Unlock();
    HAL_Delay(1);
    APP_FlashErase(0);
    HAL_Delay(1);
    APP_FlashProgram(0);
    HAL_Delay(1);
    HAL_FLASH_Lock();
    HAL_Delay(1);
    // Redundant
    HAL_FLASH_Unlock();
    HAL_Delay(1);
    APP_FlashErase(1);
    HAL_Delay(1);
    APP_FlashProgram(1);
    HAL_Delay(1);
    HAL_FLASH_Lock();
    HAL_Delay(1);

    flash_needs_update = false;
}
int main(void)
{
    HAL_Init();

    APP_SystemClockConfig();
    // XXX: This conflicts with uart pins
    APP_LedConfig();
    init_buttons();
    uart_init(front, tx);
    uart_init(back, rx);

    // IWDG_HandleTypeDef hiwdg = {0};
    // hiwdg.Instance = IWDG;
    // hiwdg.Init.Prescaler = IWDG_PRESCALER_4;
    // hiwdg.Init.Reload = 0xF;
    // HAL_IWDG_Init(&hiwdg);
    // HAL_IWDG_Refresh(&hiwdg);

    HAL_Delay(100);
    uart_send_byte(front, 'b');

    // Copy flash into the buffer
    uint32_t *flash_program_start = (uint32_t *)FLASH_USER_START_ADDR;
    for (int x = 0; x < SETTING_SIZE; x++) {
        Settings[x] = flash_program_start[x];
    }
    // Corrupt flash! Read the redundant page
    if (Settings[FLASHVALID_INDEX] != VALID_FLAG) {
        uint32_t *flash_program_start_two = (uint32_t *)FLASH_USER_START_ADDR_REDUNDANT;
        for (int x = 0; x < SETTING_SIZE; x++) {
            Settings[x] = flash_program_start_two[x];
        }
    }
    // Either way should be "valid" now
    Settings[FLASHVALID_INDEX] = VALID_FLAG;

    while (1) {
        check_buttons();
        if (flash_needs_update) {
            update_flash();
        }

        // TODO: Try a server response approach. Only do action if instructed - but break to check buttons
        //                      .... Wait a second if we poll more frequently than a human button push we don't need to break...
        //  Use half duplex uart approach!
        //  Wait on front uart query
        //  Forward to back uart
        //  Wait on back uart response
        //  Check button states
        //  Add to payload and forward to front uart

        // front_uart_init_rx();
        uart_init(front, rx);
        // val = front_uart_rx();
        uint8_t query_char = uart_rx_byte(front);
        // Don't need a specific val just trigger on anything
        #if DEBUG
        HAL_Delay(5000);
        #endif
        // back_uart_init_tx();
        uart_init(back, tx);
        // back_uart_send(query_char);
        uart_send_byte(back, query_char);
        // back_uart_init_rx();
        uart_init(back, rx);
        // 12 buttons per chip so two bytes each when packed
        uint8_t num_loops = (MAX_CALENDAR_CHIP_ID - CALENDAR_CHIP_ID) * 2;
        for (int x = 0; x < num_loops; x++) {
            // back_uart_rx()
            payload[x] = uart_rx_byte(back);
        }
        // check_buttons();
        check_buttons();
        if (flash_needs_update) {
            update_flash();
        }

        // front_uart_init_tx();
        uart_init(front, tx);
        // for (expected_len) {
        for (int x = 0; x < num_loops; x++) {
            // front_uart_tx(payload[x]);
            uart_send_byte(front, payload[x]);
            HAL_Delay(5);
#if DEBUG
            uart_print_byte(payload[x]);
            HAL_Delay(5);
#endif
        }

        // Pack the buttons into two bytes
        // Use the lower bits where timing isn't compounded
        uint8_t byte1 = 0;
        uint8_t byte2 = 0;
        for (int x = 0; x < NUM_BUTTONS / 2; x++) {
            if (Settings[x]) {
                byte1 = byte1 | (1 << x);
            }
            if (Settings[NUM_BUTTONS / 2 + x]) {
                byte2 = byte2 | (1 << x);
            }
        }
        uart_send_byte(front, byte1);
        HAL_Delay(5);
#if DEBUG
        uart_print_byte(byte1);
        HAL_Delay(5);
#endif
        uart_send_byte(front, byte2);
        HAL_Delay(5);
#if DEBUG
        uart_print_byte(byte2);
        HAL_Delay(5);
#endif
        HAL_Delay(10);
    }
}

void uart_print_byte(uint8_t data)
{
    HAL_Delay(1);

    if (data < 100) {
        uart_send_byte(front, '0');
    } else if (data < 200) {
        uart_send_byte(front, '1');
        data = data - 100;
    } else {
        uart_send_byte(front, '2');
        data = data - 200;
    }

    HAL_Delay(1);

    if (data < 10) {
        uart_send_byte(front, '0');
    } else if (data < 20) {
        uart_send_byte(front, '1');
        data = data - 10;
    } else if (data < 30) {
        uart_send_byte(front, '2');
        data = data - 20;
    } else if (data < 40) {
        uart_send_byte(front, '3');
        data = data - 30;
    } else if (data < 50) {
        uart_send_byte(front, '4');
        data = data - 40;
    } else if (data < 60) {
        uart_send_byte(front, '5');
        data = data - 50;
    } else if (data < 70) {
        uart_send_byte(front, '6');
        data = data - 60;
    } else if (data < 80) {
        uart_send_byte(front, '7');
        data = data - 70;
    } else if (data < 90) {
        uart_send_byte(front, '8');
        data = data - 80;
    } else {
        uart_send_byte(front, '9');
        data = data - 90;
    }

    HAL_Delay(500);

    if (data == 0) {
        uart_send_byte(front, '0');
    } else if (data == 1) {
        uart_send_byte(front, '1');
    } else if (data == 2) {
        uart_send_byte(front, '2');
    } else if (data == 3) {
        uart_send_byte(front, '3');
    } else if (data == 4) {
        uart_send_byte(front, '4');
    } else if (data == 5) {
        uart_send_byte(front, '5');
    } else if (data == 6) {
        uart_send_byte(front, '6');
    } else if (data == 7) {
        uart_send_byte(front, '7');
    } else if (data == 8) {
        uart_send_byte(front, '8');
    } else if (data == 9) {
        uart_send_byte(front, '9');
    } else {
        uart_send_byte(front, '!');
    }
}

static void APP_LedConfig(void)
{
    GPIO_InitTypeDef GPIO_InitStruct;

    __HAL_RCC_GPIOF_CLK_ENABLE();

    GPIO_InitStruct.Pin = GPIO_PIN_0;
    GPIO_InitStruct.Mode = GPIO_MODE_OUTPUT_PP;
    GPIO_InitStruct.Pull = GPIO_PULLUP;
    GPIO_InitStruct.Speed = GPIO_SPEED_FREQ_HIGH;

    HAL_GPIO_Init(GPIOF, &GPIO_InitStruct);
}
static void APP_SystemClockConfig(void)
{
    RCC_OscInitTypeDef RCC_OscInitStruct = {0};
    RCC_ClkInitTypeDef RCC_ClkInitStruct = {0};

    RCC_OscInitStruct.OscillatorType = RCC_OSCILLATORTYPE_HSE | RCC_OSCILLATORTYPE_HSI
#if defined(RCC_LSE_SUPPORT)
                                       | RCC_OSCILLATORTYPE_LSE
#endif
                                       | RCC_OSCILLATORTYPE_LSI;
    RCC_OscInitStruct.HSIState = RCC_HSI_ON;                          /* HSI ON */
    RCC_OscInitStruct.HSICalibrationValue = RCC_HSICALIBRATION_24MHz; /* Set HSI clock 24MHz */
    RCC_OscInitStruct.HSIDiv = RCC_HSI_DIV1;                          /* No division */
    RCC_OscInitStruct.HSEState = RCC_HSE_OFF;                         /* OFF */
    RCC_OscInitStruct.LSIState = RCC_LSI_OFF;                         /* OFF */
#if defined(RCC_LSE_SUPPORT)
    RCC_OscInitStruct.LSEState = RCC_LSE_OFF; /* OFF */
#endif
#if defined(RCC_LSE_SUPPORT)
    RCC_OscInitStruct.PLL.PLLState = RCC_PLL_OFF; /* OFF */
#endif

    if (HAL_RCC_OscConfig(&RCC_OscInitStruct) != HAL_OK) {
        APP_ErrorHandler();
    }

    /* Reinitialize AHB,APB bus clock */
    RCC_ClkInitStruct.ClockType = RCC_CLOCKTYPE_HCLK | RCC_CLOCKTYPE_SYSCLK | RCC_CLOCKTYPE_PCLK1;
    RCC_ClkInitStruct.SYSCLKSource = RCC_SYSCLKSOURCE_HSI; /* Select HSI as SYSCLK source */
    RCC_ClkInitStruct.AHBCLKDivider = RCC_SYSCLK_DIV1;     /* APH clock, no division */
    RCC_ClkInitStruct.APB1CLKDivider = RCC_HCLK_DIV1;      /* APB clock, no division */

    if (HAL_RCC_ClockConfig(&RCC_ClkInitStruct, FLASH_LATENCY_0) != HAL_OK) {
        APP_ErrorHandler();
    }
}

static void APP_FlashErase(uint8_t page)
{
    uint32_t SECTORError = 0;
    FLASH_EraseInitTypeDef EraseInitStruct;
    // Erase type = sector
    EraseInitStruct.TypeErase = FLASH_TYPEERASE_PAGEERASE;
    // Erase address start
    if (page == 0) {
        EraseInitStruct.PageAddress = FLASH_USER_START_ADDR;
    } else {
        EraseInitStruct.PageAddress = FLASH_USER_START_ADDR_REDUNDANT;
    }
    // Number of sectors
    EraseInitStruct.NbPages = 1;
    // Erase
    if (HAL_FLASHEx_Erase(&EraseInitStruct, &SECTORError) != HAL_OK) {
        APP_ErrorHandler();
    }
}
static void APP_FlashProgram(uint8_t page)
{
    uint32_t flash_program_start = FLASH_USER_START_ADDR;
    uint32_t flash_program_end = FLASH_USER_START_ADDR + sizeof(Settings);
    if (page == 0) {
        flash_program_start = FLASH_USER_START_ADDR;
        flash_program_end = FLASH_USER_START_ADDR + sizeof(Settings);
    } else {
        flash_program_start = FLASH_USER_START_ADDR_REDUNDANT;
        flash_program_end = FLASH_USER_START_ADDR_REDUNDANT + sizeof(Settings);
    }
    uint32_t *src = (uint32_t *)Settings;

    while (flash_program_start < flash_program_end) {
        // Write to flash
        if (HAL_FLASH_Program(FLASH_TYPEPROGRAM_PAGE, flash_program_start, src) == HAL_OK) {
            // Move flash point to next page
            flash_program_start += FLASH_PAGE_SIZE;
            // Move data point
            src += FLASH_PAGE_SIZE / 4;
        }
    }
}
void APP_ErrorHandler(void)
{
    while (1)
        ;
}

static void init_buttons(void)
{
    GPIO_InitTypeDef GPIO_InitStruct;

    __HAL_RCC_GPIOA_CLK_ENABLE();
    __HAL_RCC_GPIOB_CLK_ENABLE();

    GPIO_InitStruct.Mode = GPIO_MODE_INPUT;
    GPIO_InitStruct.Pull = GPIO_PULLDOWN;
    GPIO_InitStruct.Speed = GPIO_SPEED_FREQ_HIGH;

    GPIO_InitStruct.Pin = GPIO_PIN_0;
    HAL_GPIO_Init(GPIOA, &GPIO_InitStruct);
    HAL_GPIO_Init(GPIOB, &GPIO_InitStruct);
    GPIO_InitStruct.Pin = GPIO_PIN_1;
    HAL_GPIO_Init(GPIOA, &GPIO_InitStruct);
    HAL_GPIO_Init(GPIOB, &GPIO_InitStruct);
    GPIO_InitStruct.Pin = GPIO_PIN_2;
    HAL_GPIO_Init(GPIOA, &GPIO_InitStruct);
    HAL_GPIO_Init(GPIOB, &GPIO_InitStruct);
    GPIO_InitStruct.Pin = GPIO_PIN_3;
    // HAL_GPIO_Init(GPIOA, &GPIO_InitStruct);
    HAL_GPIO_Init(GPIOB, &GPIO_InitStruct);
    GPIO_InitStruct.Pin = GPIO_PIN_4;
    HAL_GPIO_Init(GPIOA, &GPIO_InitStruct);
    GPIO_InitStruct.Pin = GPIO_PIN_5;
    HAL_GPIO_Init(GPIOA, &GPIO_InitStruct);
    GPIO_InitStruct.Pin = GPIO_PIN_6;
    HAL_GPIO_Init(GPIOA, &GPIO_InitStruct);
    GPIO_InitStruct.Pin = GPIO_PIN_7;
    HAL_GPIO_Init(GPIOA, &GPIO_InitStruct);
}

void button_helper(uint8_t id, GPIO_PinState status)
{
    if (status == GPIO_PIN_RESET) {
        if (Button_held[id] != 1) {
            Button_held[id] = 1;
            if (Settings[id] == 0) {
                Settings[id] = 1;
            } else {
                Settings[id] = 0;
            }
            flash_needs_update = true;
        }
    } else {
        Button_held[id] = 0;
    }
}
void check_buttons()
{
    button_helper(0, HAL_GPIO_ReadPin(GPIOB, GPIO_PIN_3));
    button_helper(1, HAL_GPIO_ReadPin(GPIOA, GPIO_PIN_5));
    button_helper(2, HAL_GPIO_ReadPin(GPIOA, GPIO_PIN_6));
    button_helper(3, HAL_GPIO_ReadPin(GPIOA, GPIO_PIN_0));
    button_helper(4, HAL_GPIO_ReadPin(GPIOA, GPIO_PIN_7));
    button_helper(5, HAL_GPIO_ReadPin(GPIOB, GPIO_PIN_0));
    button_helper(6, HAL_GPIO_ReadPin(GPIOB, GPIO_PIN_2));
    button_helper(7, HAL_GPIO_ReadPin(GPIOB, GPIO_PIN_1));
    // button_helper(8, HAL_GPIO_ReadPin(GPIOA, GPIO_PIN_3));
    button_helper(9, HAL_GPIO_ReadPin(GPIOA, GPIO_PIN_2));
    button_helper(10, HAL_GPIO_ReadPin(GPIOA, GPIO_PIN_1));
    button_helper(11, HAL_GPIO_ReadPin(GPIOA, GPIO_PIN_4));
}

// XXX: There is 0.8 us of overhead in this function! (should probably subtract by 1)
// This was created experimentally by watching an oscilloscope - it is not that accurate
void sleep_us(uint32_t us)
{
    for (volatile int x = 0; x < us; x++) {
        __asm__("nop");
        __asm__("nop");
        __asm__("nop");
        __asm__("nop");
        __asm__("nop");
        __asm__("nop");
        __asm__("nop");
        __asm__("nop");
        __asm__("nop");
        __asm__("nop");
    }
}

void uart_init(front_back fb, tx_rx txrx)
{
    // Just enable them all
    __HAL_RCC_GPIOA_CLK_ENABLE();
    __HAL_RCC_GPIOB_CLK_ENABLE();
    __HAL_RCC_GPIOF_CLK_ENABLE();

    GPIO_InitTypeDef GPIO_InitStruct;

    if (txrx == tx) {
        GPIO_InitStruct.Mode = GPIO_MODE_OUTPUT_PP;
        GPIO_InitStruct.Pull = GPIO_PULLUP;
        GPIO_InitStruct.Speed = GPIO_SPEED_FREQ_HIGH;
        if (fb == front) {
            GPIO_InitStruct.Pin = CALENDAR_FRONT_UART_PIN;
            HAL_GPIO_Init(CALENDAR_FRONT_UART_MODULE, &GPIO_InitStruct);
            HAL_GPIO_WritePin(CALENDAR_FRONT_UART_MODULE, CALENDAR_FRONT_UART_PIN, GPIO_PIN_SET); // Initialize TX pin high (idle state)
        } else {
            GPIO_InitStruct.Pin = CALENDAR_BACK_UART_PIN;
            HAL_GPIO_Init(CALENDAR_BACK_UART_MODULE, &GPIO_InitStruct);
            HAL_GPIO_WritePin(CALENDAR_BACK_UART_MODULE, CALENDAR_BACK_UART_PIN, GPIO_PIN_SET); // Initialize TX pin high (idle state)
        }
    } else {
        GPIO_InitStruct.Mode = GPIO_MODE_INPUT;
        GPIO_InitStruct.Pull = GPIO_NOPULL;
        GPIO_InitStruct.Speed = GPIO_SPEED_FREQ_HIGH;
        if (fb == front) {
            GPIO_InitStruct.Pin = CALENDAR_FRONT_UART_PIN;
            HAL_GPIO_Init(CALENDAR_FRONT_UART_MODULE, &GPIO_InitStruct);
        } else {
            GPIO_InitStruct.Pin = CALENDAR_BACK_UART_PIN;
            HAL_GPIO_Init(CALENDAR_BACK_UART_MODULE, &GPIO_InitStruct);
        }
    }
}

void uart_send_byte(front_back fb, uint8_t data)
{

    GPIO_TypeDef *GPIO_Module;
    uint16_t GPIO_Pin;
    if (fb == front) {
        GPIO_Module = CALENDAR_FRONT_UART_MODULE;
        GPIO_Pin = CALENDAR_FRONT_UART_PIN;
    } else {
        GPIO_Module = CALENDAR_BACK_UART_MODULE;
        GPIO_Pin = CALENDAR_BACK_UART_PIN;
    }
    // Start bit (low)
    HAL_GPIO_WritePin(GPIO_Module, GPIO_Pin, GPIO_PIN_RESET);
    sleep_us(1000000 / BAUD_RATE); // Delay to match baud rate

    // Send data bits (LSB first)
    for (int i = 0; i < 8; i++) {
        if ((data >> i) & 1) {
            HAL_GPIO_WritePin(GPIO_Module, GPIO_Pin, GPIO_PIN_SET);
        } else {
            HAL_GPIO_WritePin(GPIO_Module, GPIO_Pin, GPIO_PIN_RESET);
        }
        sleep_us(1000000 / BAUD_RATE); // Delay to match baud rate
    }

    // Stop bit (high)
    HAL_GPIO_WritePin(GPIO_Module, GPIO_Pin, GPIO_PIN_SET);
    // Just make sure we're high for long enough
    sleep_us(1000000 / BAUD_RATE); // Delay to match baud rate
    sleep_us(1000000 / BAUD_RATE); // Delay to match baud rate
    sleep_us(1000000 / BAUD_RATE); // Delay to match baud rate
    sleep_us(1000000 / BAUD_RATE); // Delay to match baud rate
    sleep_us(1000000 / BAUD_RATE); // Delay to match baud rate
}

uint8_t uart_rx_byte(front_back fb)
{
    uint8_t data = 0;

    GPIO_TypeDef *GPIO_Module;
    uint16_t GPIO_Pin;
    if (fb == front) {
        GPIO_Module = CALENDAR_FRONT_UART_MODULE;
        GPIO_Pin = CALENDAR_FRONT_UART_PIN;
    } else {
        GPIO_Module = CALENDAR_BACK_UART_MODULE;
        GPIO_Pin = CALENDAR_BACK_UART_PIN;
    }

    // Wait for start bit
    uint32_t ticks = HAL_GetTick();
    while (HAL_GPIO_ReadPin(GPIO_Module, GPIO_Pin) == GPIO_PIN_SET) {
        // If we roll over it's unsigned so the number will be really big and we'll just loop instantly one time
        // Looping every doesn't seem to matter anyway, though not sure with writing to flash... Meh just update flash outside of this loop
        if (HAL_GetTick() - ticks > 10) {
            ticks = HAL_GetTick();
            check_buttons();
            // if (flash_needs_update) {
            //     update_flash();
            // }
        }
    }

    ////HAL_GPIO_WritePin(CALENDAR_UART_TX_MODULE, CALENDAR_UART_TX, GPIO_PIN_RESET);

    // Wait for half a bit period and sample in the middle of the bit
    sleep_us(1000000 / (2 * BAUD_RATE));
    sleep_us(1000000 / (BAUD_RATE));

    // Receive data bits (LSB first)
    for (int i = 0; i < 8; i++) {
        data |= (HAL_GPIO_ReadPin(GPIO_Module, GPIO_Pin) << i);
        ////HAL_GPIO_WritePin(CALENDAR_UART_TX_MODULE, CALENDAR_UART_TX, HAL_GPIO_ReadPin(CALENDAR_UART_RX_MODULE, CALENDAR_UART_RX));
        sleep_us(1000000 / BAUD_RATE); // Delay to match baud rate
    }

    // HAL_GPIO_WritePin(CALENDAR_UART_TX_MODULE, CALENDAR_UART_TX, GPIO_PIN_SET);

    // Wait for stop bit
    // TODO: timeout if we get stuck?... I mean it all has to work to work so *shrug*...
    while (HAL_GPIO_ReadPin(GPIO_Module, GPIO_Pin) == GPIO_PIN_RESET) {
    }

    ////HAL_GPIO_WritePin(CALENDAR_UART_TX_MODULE, CALENDAR_UART_TX, GPIO_PIN_SET);

    return data;
}
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

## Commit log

2023-04-21 Initial commit. Import py32f002a part form easyeda2kicad
    [habit-calendar.kicad_pcb, habit-calendar.kicad_sch]
2023-04-22 Place components about to start routing.
    [habit-calendar.kicad_pcb, habit-calendar.kicad_sch]
2023-04-24 One micor ready. About to double the board.
    [habit-calendar.kicad_pcb, habit-calendar.kicad_sch]
2023-04-25 Got it. Just needs a logo.
    [habit-calendar.kicad_pcb, habit-calendar.kicad_sch]
2023-04-25 small tweaks but still single board. might change up edge connector
    [habit-calendar.kicad_pcb]
2023-04-26 Moved to a new heirarchical sheet. Instantiated two. Some PCB tweeks. Added Logo. Now going to use the replicate plugin to make another copy.
    [habit-calendar-subsheet-for-replica.kicad_sch, habit-calendar.kicad_pcb, habit-calendar.kicad_sch]
2023-04-26 Sent to production!
    [BOM-habit-calendar.csv, habit-calendar-subsheet-for-replica.kicad_sch, habit-calendar.kicad_pcb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]
2023-09-17 Add pico master to readme.
2023-09-18 Update readme and code for pico-master. Untested blocking bitbang uart
2023-09-18 Update readme with instructions on using 3.3V
2023-09-19 Working bitbanged uart at 9600 baud
2023-09-19 More accurate baudrate to fix errors.
    [main.c]
2023-09-21 Two half duplex uarts!
2023-09-21 Check buttons even when waiting for rx!
2023-09-22 Changed based on ID - make printing bytes its own helper function
